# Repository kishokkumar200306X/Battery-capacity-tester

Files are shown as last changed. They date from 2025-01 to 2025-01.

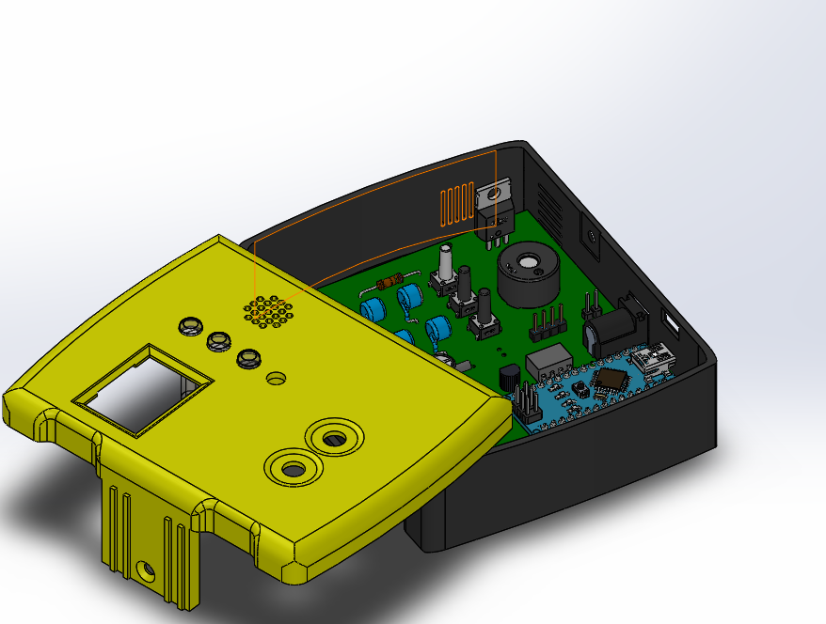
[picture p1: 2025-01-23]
image/Screenshot 2023-06-16 191335.png

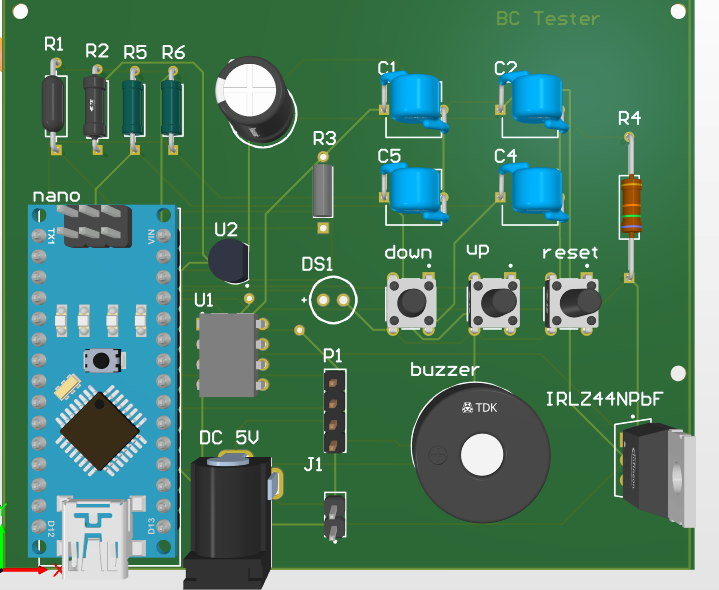
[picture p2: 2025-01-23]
image/Screenshot 2023-07-24 213903.png

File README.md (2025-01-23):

# Battery Capacity Tester

## Overview  
The Battery Capacity Tester is a digital device that allows users to measure the capacity of various battery types. It is designed for household use and works with nearly all batteries rated below 5V. The device features an OLED display for real-time monitoring and provides audible signals to indicate the start and end of the testing process.

## Main Functionality  
1. **Setup**  
   - Connect the battery to the battery terminal.  
   - Set the desired discharge current using the push buttons.  

2. **Start Test**  
   - Long-press the "UP" button until a beep is heard to start the test process.  

3. **Testing Process**  
   - The battery will discharge until its voltage reaches the low-level threshold of 3.2V.  
   - All relevant parameters (voltage, discharge current, and capacity) are displayed on the OLED during the process.  

4. **End of Test**  
   - Two prolonged beeps indicate the end of the test when the battery voltage drops to 3.2V.

Battrey capacity tester   

## Features  
- Supports a wide range of battery types:  
  - AA/AAA/NiMh/NiCd  
  - 18650 Li-ion  
  - Li-Polymer  
  - LiFePO4  
- Adjustable discharge current via push buttons.  
- Functions as an electronic load.  
- Real-time monitoring on a 0.96’’ I2C OLED display.  
- Audible alerts for the start and end of the test process.  

## Specifications  
- **Type**: Household battery tester  
- **Style**: Digital  
- **Power Supply**: 7–9V DC  
- **Display**: 0.96’’ I2C OLED  
- **Monitoring Parameters**:  
  - Battery voltage  
  - Discharge current  
  - Battery capacity  
- **Controls**:  
  - Three push buttons:  
    - One for resetting the Arduino  
    - Two for adjusting discharge current  
- **Buzzer**: Provides audible signals for key events.  
- **Operating Temperature**: 0°C – 40°C  

## How to Use  
1. Power the tester using a 7–9V DC power source.  
2. Connect the battery securely to the terminal.  
3. Use the push buttons to set the desired discharge current.  
4. Long-press the "UP" button to start the test.  
5. Monitor the OLED display for real-time updates on voltage, current, and capacity.  
6. Wait until the battery voltage reaches 3.2V, at which point the device will emit two prolonged beeps.  

## Notes  
- Ensure the power supply is stable and within the specified range (7–9V).  
- Operate the tester within the recommended temperature range (0°C – 40°C).  
- Handle batteries carefully to prevent short circuits or damage.  

---

**Enjoy accurate and efficient battery capacity testing with this versatile device!**

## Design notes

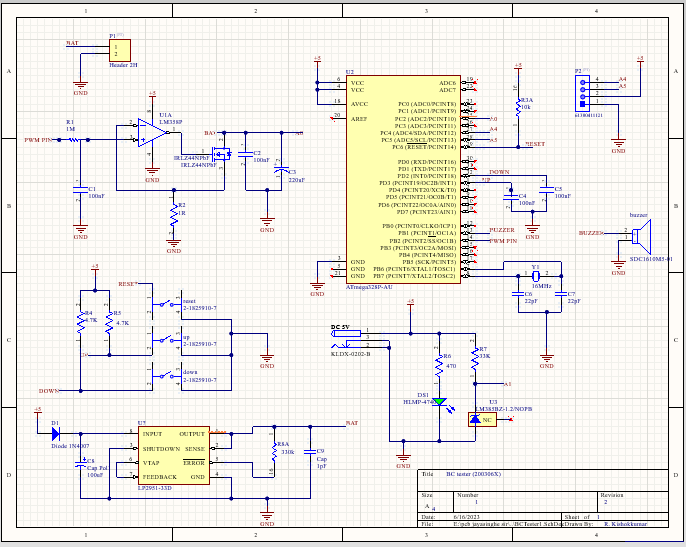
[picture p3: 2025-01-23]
image/Screenshot 2023-06-16 203310.png

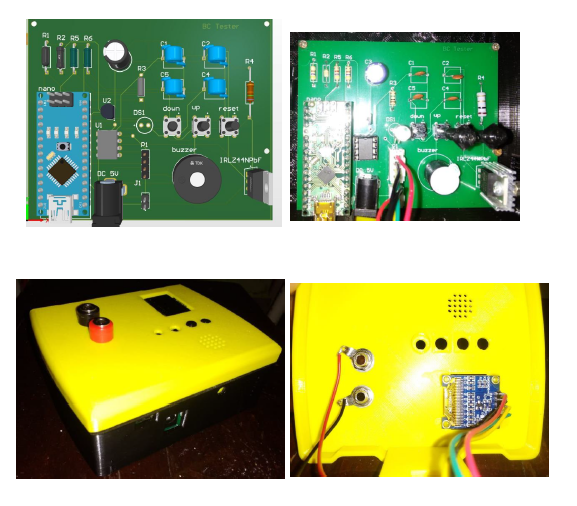
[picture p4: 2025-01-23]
image/implemeted .png

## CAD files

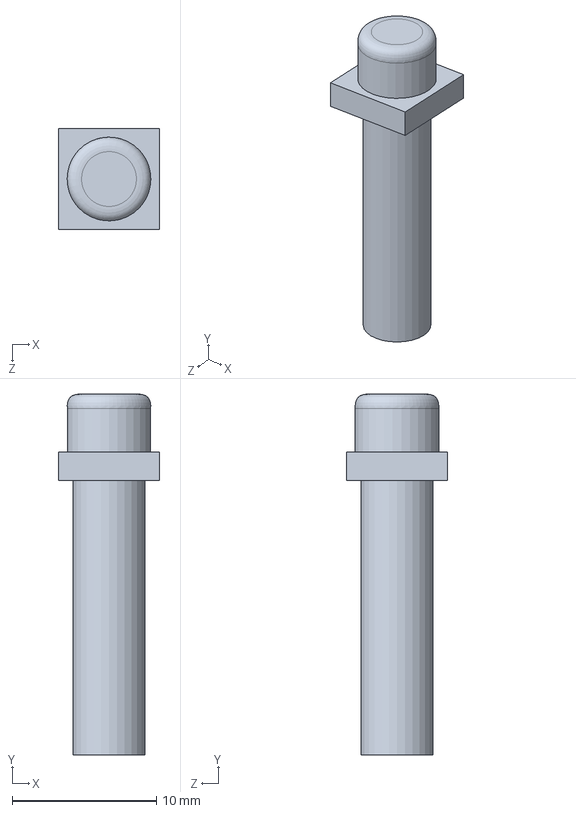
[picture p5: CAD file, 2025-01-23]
Enclosure design - solidworks/new sw.SLDPRT
7.00 x 25.0 x 7.00 mm

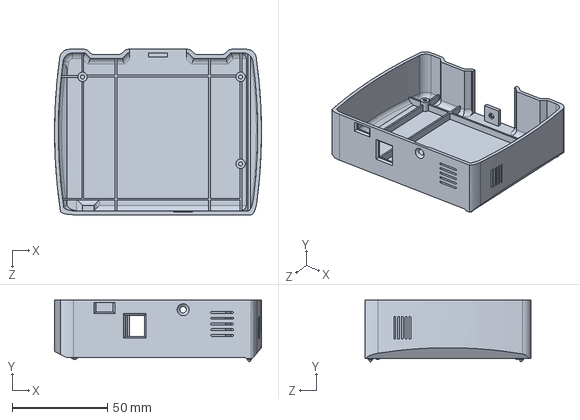
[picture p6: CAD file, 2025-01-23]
Enclosure design - solidworks/base.SLDPRT
108.8 x 32.4 x 87.0 mm

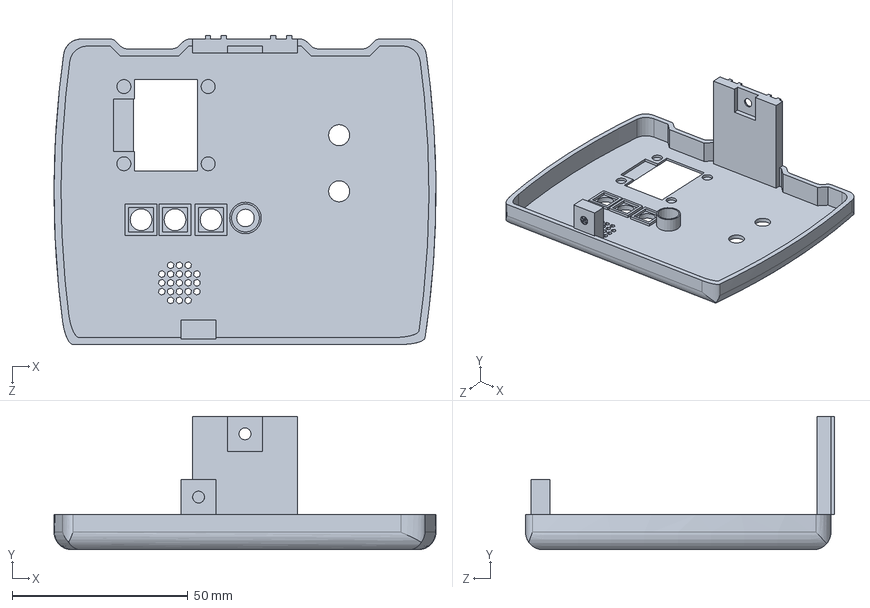
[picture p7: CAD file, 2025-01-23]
Enclosure design - solidworks/lid.SLDPRT
108.8 x 38.0 x 88.0 mm

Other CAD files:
Enclosure design - solidworks/base.STL
Enclosure design - solidworks/lid.STL
Enclosure design - solidworks/new sw.STL

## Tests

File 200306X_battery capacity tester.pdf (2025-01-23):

BATTERY CAPACITY TESTER

### DEPARTMENT OF ELECTRONICS AND TELECOMMUNICATION ENGINEERING

### UNIVERSITY OF MORATUWA

# EN2160 - Electronic Design Realization

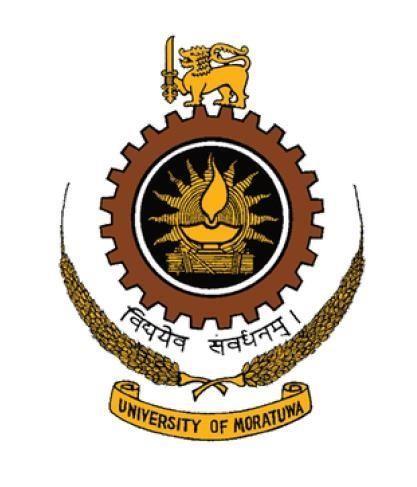
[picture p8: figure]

# Battery capacity tester

# Final Report

Kishokkumar R. – 200306X

## Main Function

The battery must be connected to the battery terminal. Long-press the "UP" button after setting the current to your specifications. The test procedure should then begin after hearing a beep. You will keep an eye on every parameter on the OLED display throughout the exam. Until its voltage approaches its low-level threshold, the battery will deplete. (3.2V). Two prolonged sounds will signal the end of the test process.

Features
Able to gauge AA/AA/NiMh/NiCd, 18650 Li-ion, Li-Polymer, and Li FePO4 battery capacities. It works with nearly all batteries with a rating of less than 5V. Pushbuttons can be used by users to adjust the discharge current.
User interface OLED
The gadget is capable of being an electronic load.

## Specifications

Type – household battery tester Style - digital
7-9V power supply required.
0.96’’ I2C OLED display.
Display battery voltage, Discharge current and Capacity.
Consists Three push buttons. One is use for reset the Arduino.
There is a buzzer
It indicates start and end of the test.
Working temperature : 0°C - 40°C

Product reference :
https://www.aliexpress.com/item/1005005105860242.html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 54628ea-1ad6-48d9-ad37-c57765e4c48d-16&pdp_npi=3%40dis%21LKR%2127385.19%2116431.76%21%21%21%21%21%40211bd7d61681041421921 8009d07f1%2112000031679811352%21sea%21LK%210&curPageLogUid=IA2RPzbEf1A6&ad_pvid=202 304090457014900265934220240003583604_17&ad_pvid=20230409045701490026593422024000 3583604_17 (https://www.aliexpress.com/item/1005005105860242.html?curPageLogUid=IA2RPzbEf1A6)

## Theory

The hypothesis is based on the voltage comparison of the OpAmp's unity amplifier-configured inverting (pin 2) and non-inverting (pin 3) inputs. The output of the opamp opens the gate of the MOSFET when the voltage applied to the non-inverting input is set by modifying the PWM signal. OpAmp receives negative feedback as the MOSFET turns on because of the voltage drop caused by the current flowing through R1 during this process. It manages the MOSFET in a way that ensures an identical voltage at both its inverting and non-inverting inputs. As a result, the voltage at the OpAmp's non-inverting input is directly proportional to the current flowing through the load resistor.

## Block diagram

User interface | outputs

Constant
current load
circuit

Arduino
nano board
Battery
voltage
measurement
circuit(voltage
sensing)

230V AC to 5V DC
Power supply

oled
display

3 -
switches[up,
down,reset]
(input)

Battery
terminals
(input)

Buzzer
circuit

## Pcb design files

Link for pcb design files- https://dms.uom.lk/s/4QDM4L8Pabeeqjx

1. Schematic design

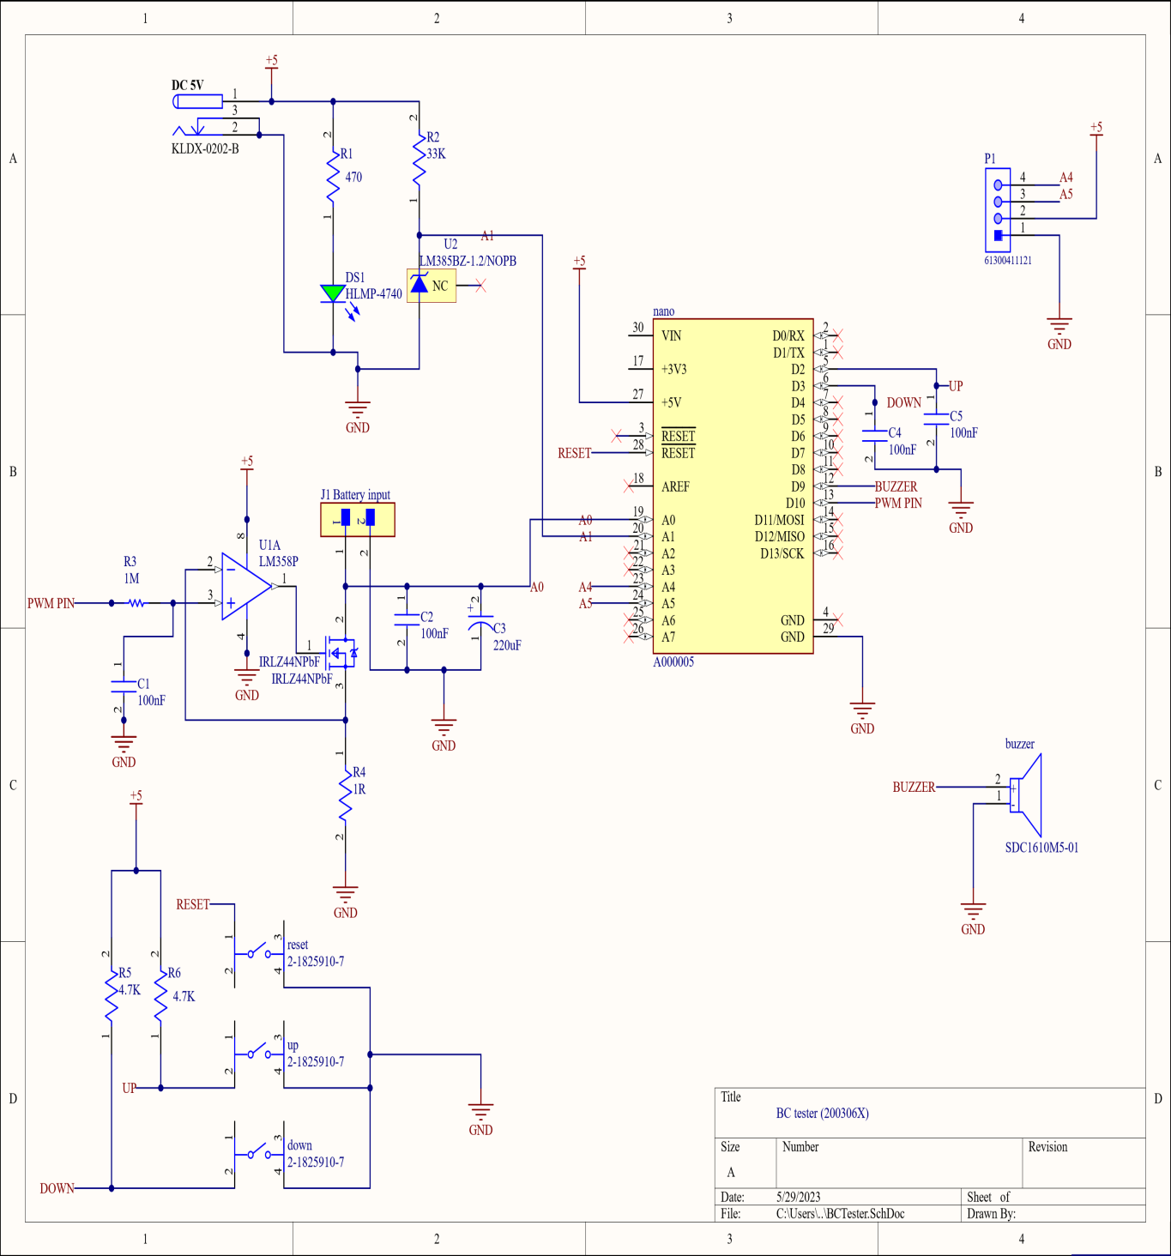
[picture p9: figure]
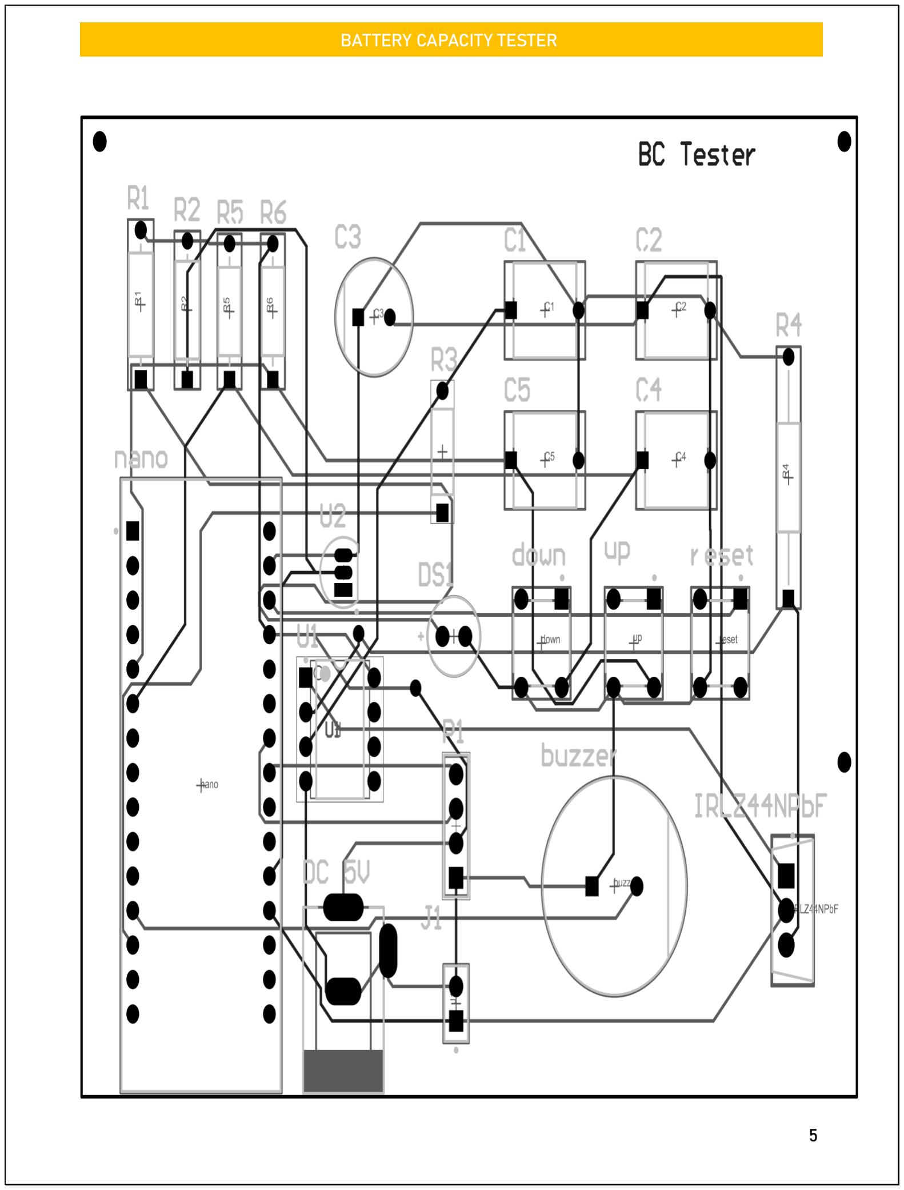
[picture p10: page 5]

## The following sections comprise the entire schematic:

1. A circuit with a constant current load

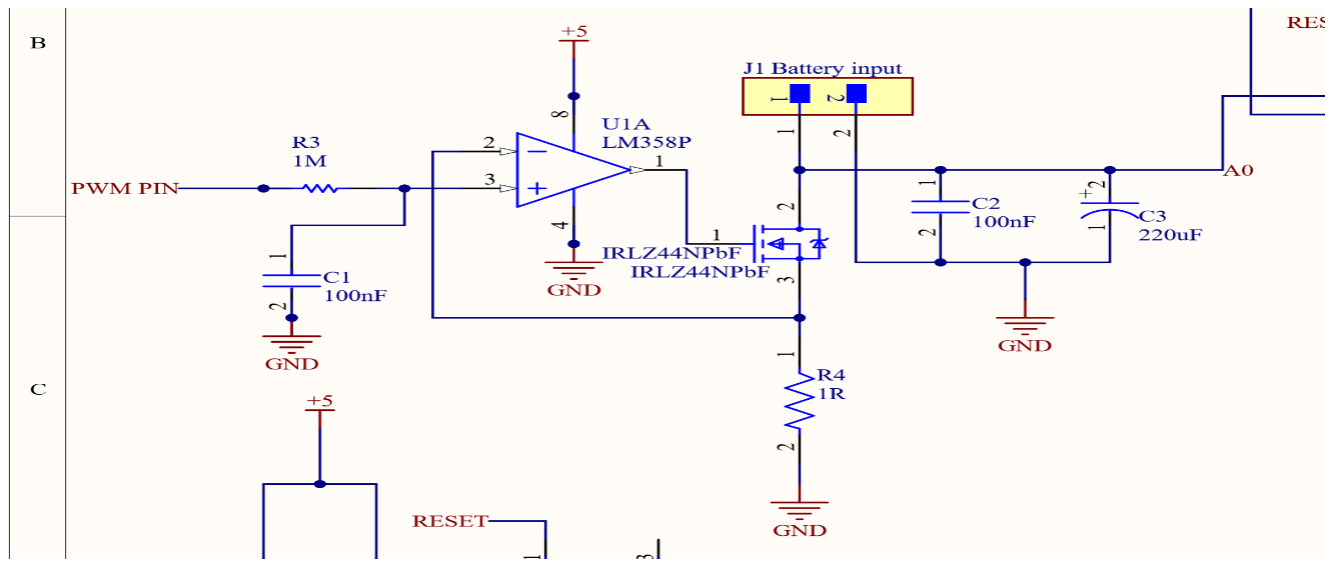
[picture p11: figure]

The LM358 dual amplifier is the project's major part. In a single box, the LM358 has two amplifiers. Only one op-amp is necessary for this project, though. The first operational amplifier's non-inverted pin is linked to the PWM output of Arduino Pin D10. To obtain an equivalent analogue voltage, the PWM is filtered using R3 and C1's low pass filter. The operational amplifier, which is linked to the IRLZ44N MOSFET source pin and the 1R shunt resistor (R4), receives feedback from the inverting input.

A constant current load circuit is created by this op-amp, R4, and the MOSFET. The opamp activates the MOSFET and tries to get the same voltage across R4 when the non-inverting input pin voltage is set. Because of Ohm's rule, a voltage drop must occur while current travels through the resistor. We can now adjust the PWM signal pulse width to control the current flowing through the load resistor (R3).

2. Circuit for Measuring Battery Voltage -

The Arduino's analogue input pin A0 measures the voltage of the battery. The constant current load circuit sounds, which can impair the efficiency of the ADC conversion, are filtered off using two capacitors, C2 and C3.

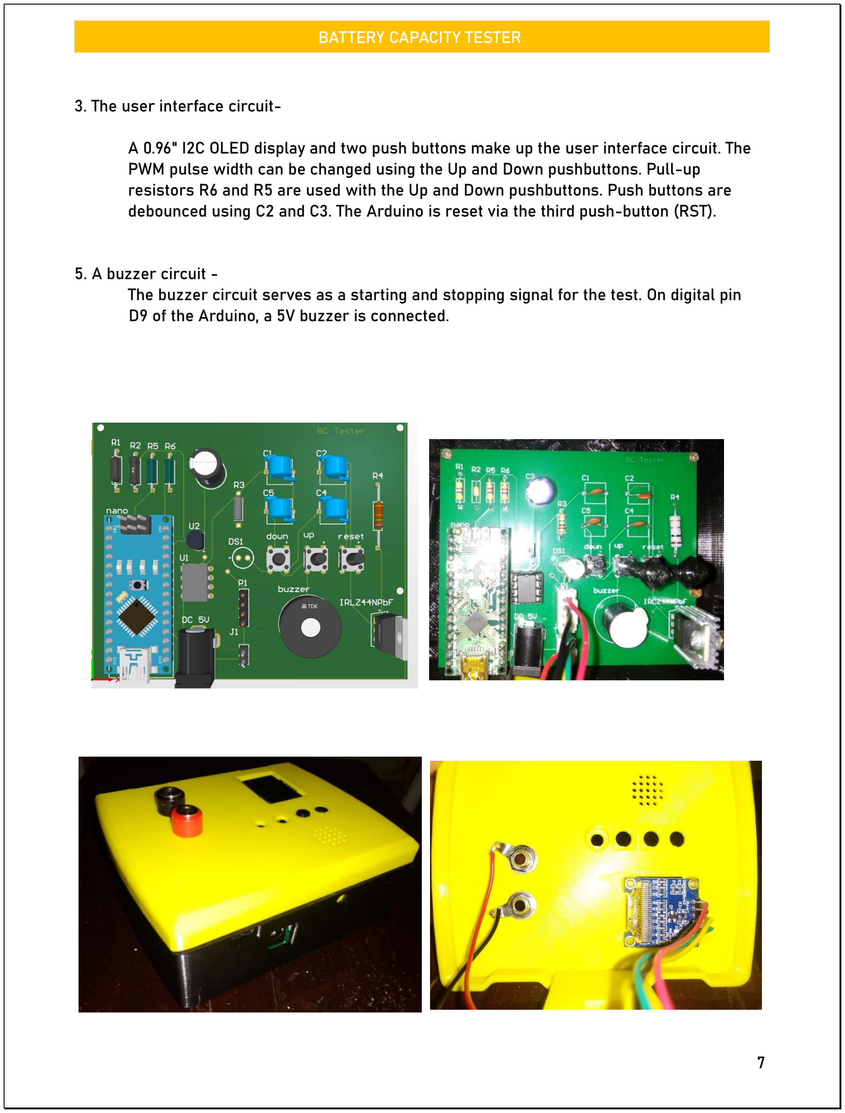
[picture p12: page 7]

3. The user interface circuit-

A 0.96" I2C OLED display and two push buttons make up the user interface circuit. The PWM pulse width can be changed using the Up and Down pushbuttons. Pull-up resistors R6 and R5 are used with the Up and Down pushbuttons. Push buttons are debounced using C2 and C3. The Arduino is reset via the third push-button (RST).

5. A buzzer circuit -
The buzzer circuit serves as a starting and stopping signal for the test. On digital pin D9 of the Arduino, a 5V buzzer is connected.

## Bill of materials

Mouser # | link | quantity | price | Manufacturer
782-A000005 | https://www.mouser.com
| /ProductDetail/782- A000005 (https://www.mouser.com/ProductDetail/782-A000005)
1 | $24.90
| | | | Arduino
926-LM385BZ- 12/NOPB | https://www.mouser.com
| /ProductDetail/926-
| LM385BZ-12-NOPB (https://www.mouser.com/ProductDetail/926-LM385BZ-12-NOPB)
3 | $3.48
| | | | Texas Instruments
595-LM358P | https://www.mouser.com
| /ProductDetail/595-
| LM358P (https://www.mouser.com/ProductDetail/595-LM358P)
4 | $1.52
| | | | Texas Instruments
942-IRLZ44NPBF | https://www.mouser.com
| /ProductDetail/942-
| IRLZ44NPBF (https://www.mouser.com/ProductDetail/942-IRLZ44NPBF)
2 | $3.32
| | | | Infineon
187- CL05A104KA5NN NC | https://www.mouser.com
| /ProductDetail/187-
| CL05A104KA5NNNC (https://www.mouser.com/ProductDetail/187-CL05A104KA5NNNC)
10 | $0.11
| | | | Samsung Electro-
| | | | Mechanics
80- ESK227M016AG3 DA | https://www.mouser.com /ProductDetail/80-
| ESK227M016AG3DA (https://www.mouser.com/ProductDetail/80-ESK227M016AG3DA)
10 | $2.57
| | | | KEMET
490-CMI-1295- 0585T | https://www.mouser.com
| /ProductDetail/490-CMI-
| 1295-0585T (https://www.mouser.com/ProductDetail/490-CMI-1295-0585T)
1 | $1.18
| | | | CUI Devices
708-CF14JT1M00 | https://www.mouser.com
| /ProductDetail/708-
| CF14JT1M00 (https://www.mouser.com/ProductDetail/708-CF14JT1M00)
10 | $0.31
| | | | SEI Stackpole
660- CFS1/4CT52R333J | https://www.mouser.com
| /ProductDetail/660-CFS1-
| 4CT52R333J (https://www.mouser.com/ProductDetail/660-CFS1-4CT52R333J)
10 | $0.46
| | | | KOA Speer
708-CF14JT4K70 | https://www.mouser.com
| /ProductDetail/708- CF14JT4K70 (https://www.mouser.com/ProductDetail/708-CF14JT4K70)
10 | $0.31
| | | | SEI Stackpole
279-CFR100J1M0 | https://www.mouser.com
| /ProductDetail/279-
| CFR100J1M0 (https://www.mouser.com/ProductDetail/279-CFR100J1M0)
10 | $2.62
| | | | TE Connectivity
815-ABLS-16.0M- T | https://www.mouser.com
| /ProductDetail/815-ABLS-
| 16.0M-T (https://www.mouser.com/ProductDetail/815-ABLS-16.0M-T)
2 | $0.64
| | | ABRACON

## Enclosure design files

Link for solidworks files - https://dms.uom.lk/s/D8EcxXdq78NAgSy

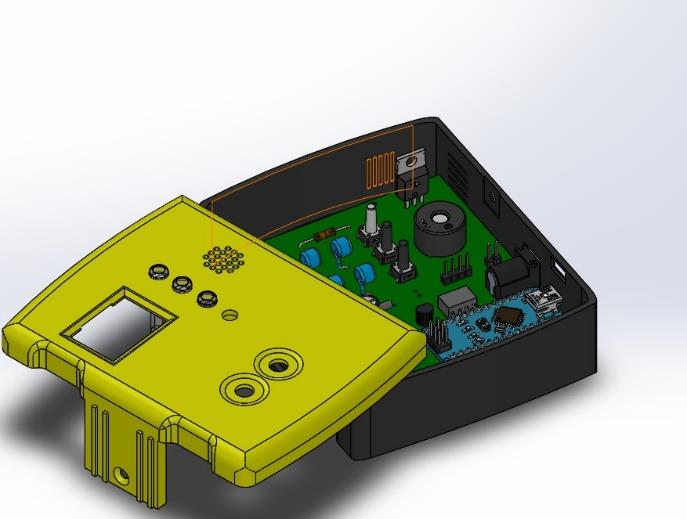
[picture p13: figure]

## Arduino codes

Link -https://dms.uom.lk/s/RrMbTZdH6JyfaTf

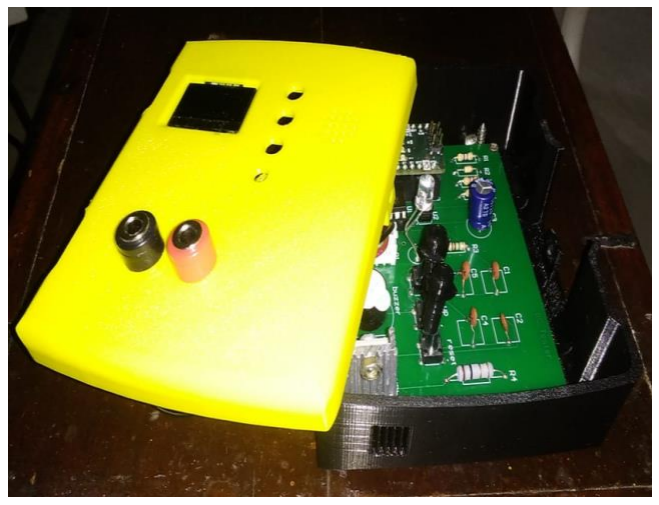
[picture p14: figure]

## User manual

### Procedure

1. Power up the device through power supply (device automatically ask to set the discharge current )

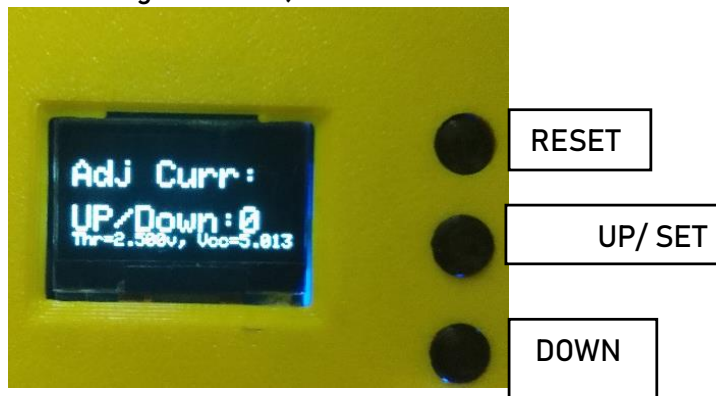
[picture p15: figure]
RESET; UP/ SET; DOWN

2. User can set discharge current according to the up and down buttons and set the discharging current through long press the up buttons.
3. Once device get the battery capacity then it will make sound to indicate it.
4. Display shows the time taken for process , instance voltage across the battery and capacity.

### Precautions

1. User should connect the terminals correctly.
2. Keep the device around 27degree Celsius environment.
3. Double-check the battery capacity tester to make sure it is appropriate for the particular battery chemistry and voltage you plan to test. Inaccurate results or battery damage can result from using the improper tester.
4. Before testing, check the battery for physical damage, leakage, or swelling. Batteries that are obviously degraded or damaged shouldn't be tested because they pose a risk.

## Maintenance procedure

For a battery capacity tester to remain accurate and dependable, proper maintenance is essential. Regular upkeep increases a device's lifespan and guarantees that it will operate properly when required. For a battery capacity tester, the following general maintenance methods are recommended:

1. Examine the manual:
a. Read the manufacturer's given user manual in its entirety first. The manual often includes detailed schedules and directions for maintenance.
2. Maintain Regular Cleaning:
a. Wipe the battery capacity tester clean by using a soft, dry cloth. Clear the device's surface of any dust, grime, or debris that may have accumulated.
3. Examine Testing Cables and Connectors:
a. Consistently look for evidence of wear, damage, or loose connections on the testing cables and connectors. In order to prevent false readings, damaged wires should be replaced right away.
4. Calibration Check:
a. As directed by the manufacturer or based on usage patterns, do routine calibration checks. The accuracy of the tester's readings is guaranteed via calibration.
5. Software update:
a. Updates to the battery capacity tester's software should be installed as needed. If the battery capacity tester has software or firmware, look for updates from the manufacturer. Software updates may enhance functionality and include new features.
6. Maintain a Proper Environment:
a. The battery capacity tester should be kept in a sterile, dry, and temperaturecontrolled environment. The device can be harmed by high or low humidity, exposure to liquids, or extreme temperatures.

7. Packaging :
a. Use a protective carrying case or storage bag, if at all possible, to keep the battery capacity tester safe during transportation and when not in use.
8. Service and repairs:
a. For maintenance and repairs on the battery capacity tester, get in touch with the manufacturer's authorised service centre. Avoid making repairs on your own as this could void the warranty or cause more harm.
9. User Handling:
a. Educate users on how to use and handle the battery capacity tester correctly. Do not drop or handle the gadget roughly as this could lead to internal damage.
10. Follow manufacturer's instructions:
a. Follow any maintenance advice the manufacturer may provide you. To ensure peak performance, they could provide particular advises or recommendations.
11. Regular Testing:
a. To ensure the battery capacity tester's accuracy, test it on a regular basis with reference batteries that are known to work. This makes it possible to detect any reading drift and make corrections as necessary.

## Performance verification

1. Reference battery test :
a. Use a set of reference batteries that are well-known, completely charged, and have capacities that have been independently validated. Record the measurements after each reference battery is connected to the tester. Compared to the reference batteries' known capacity, compare the tester's findings. Within a reasonable tolerance range, the tester should deliver readings that are somewhat near to the known values.
2. Verification with New Batteries:
a. Utilise the capacity tester to test new batteries with the appropriate capacities. For the batteries being tested, the measurements must closely resemble the capacity specified by the manufacturer.
3. Test for repeatability:
a. Run the same battery through several tests in a row, then compare the findings. The readings ought to be reliable and barely deviate.
4. Linearity test:
a. Test batteries' linearity using a range of capacities, from low to high. The readings from the tester should show a linear relationship with the tested battery capacity.
5. Temperature sensitivity:
a. Test batteries' sensitivity to temperature variations within the device's operational range. Regardless of temperature variations, the tester should display consistent values.
6. Internal Battery Test:
a. If the battery capacity tester includes a built-in battery for backup power, regularly check its capacity to make sure it has enough power.

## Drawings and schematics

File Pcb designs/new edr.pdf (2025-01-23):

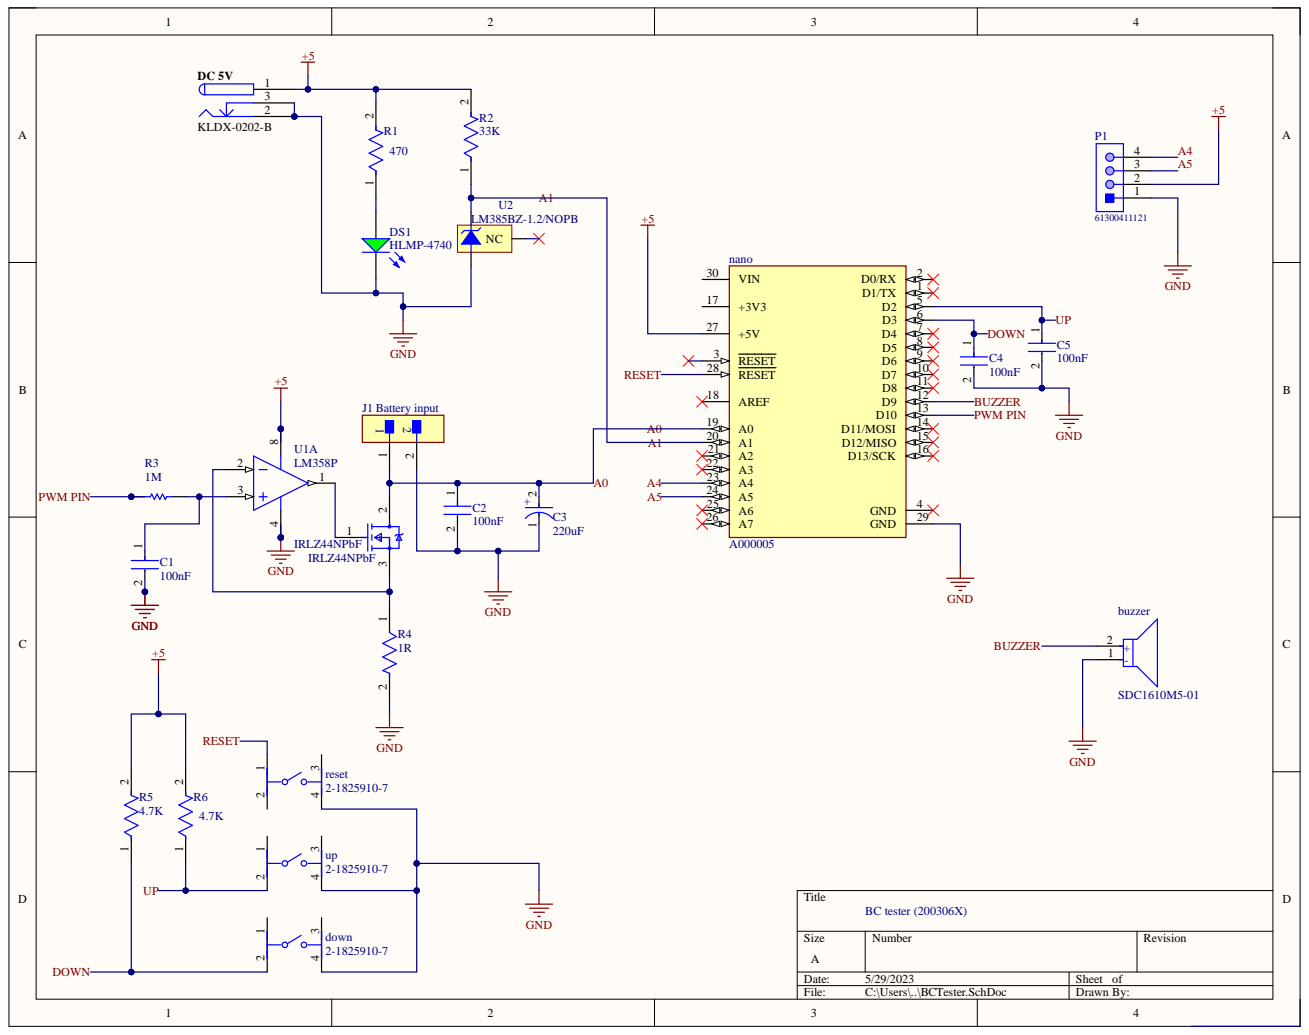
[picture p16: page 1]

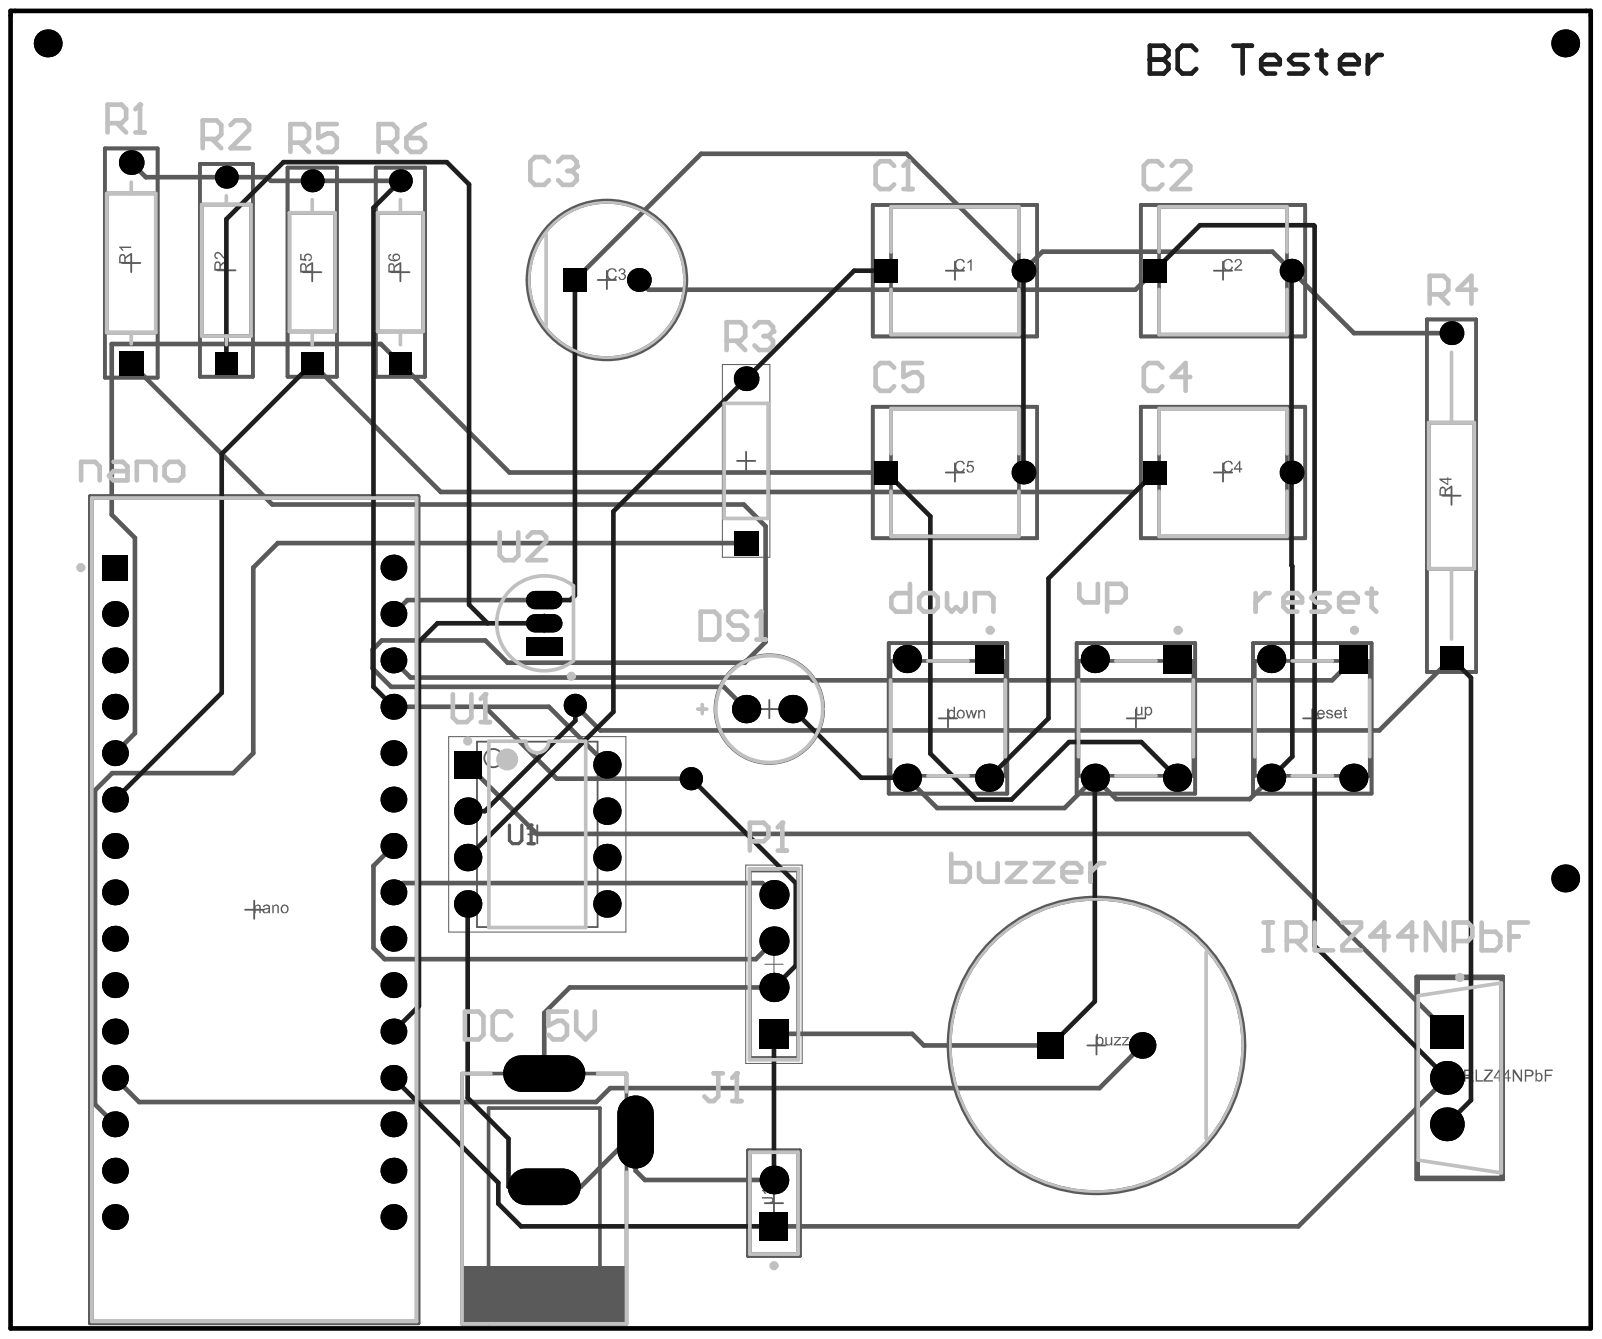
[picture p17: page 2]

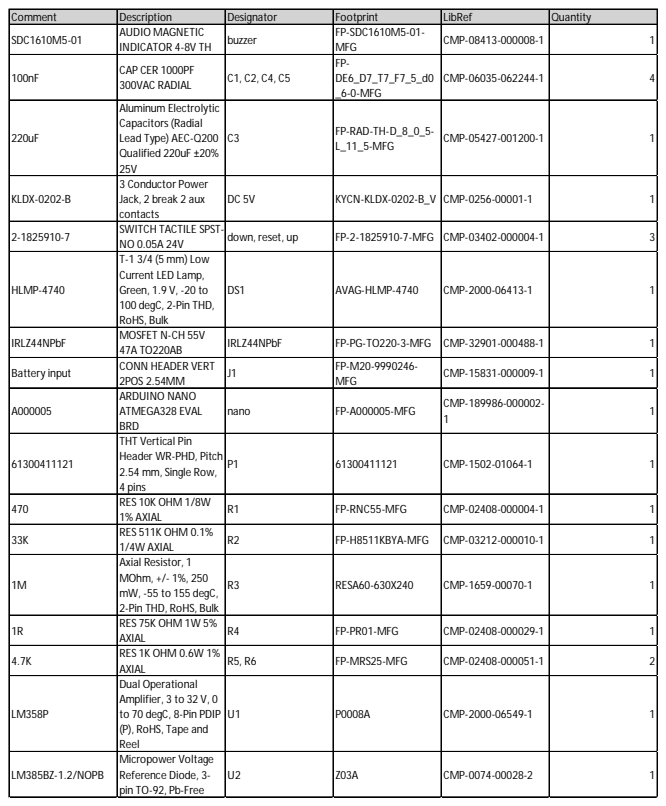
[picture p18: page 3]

Comment | Description | Designator | Footprint | LibRef | Quantity
SDC1610M5-01 | AUDIO MAGNETIC INDICATOR 4-8V TH | buzzer | FP-SDC1610M5-01-MFG | CMP-08413-000008-1 | 1

100nF | CAP CER 1000PF 300VAC RADIAL | C1, C2, C4, C5 | FP-DE6_D7_T7_F7_5_d0 _6-0-MFG | CMP-06035-062244-1 | 4

220uF | Aluminum Electrolytic Capacitors (Radial Lead Type) AEC-Q200 Qualified 220uF ±20% 25V | C3 | FP-RAD-TH-D_8_0_5-L_11_5-MFG | CMP-05427-001200-1 | 1

KLDX-0202-B | 3 Conductor Power Jack, 2 break 2 aux contacts | DC 5V | KYCN-KLDX-0202-B_V | CMP-0256-00001-1 | 1

2-1825910-7 | SWITCH TACTILE SPST-NO 0.05A 24V | down, reset, up | FP-2-1825910-7-MFG | CMP-03402-000004-1 | 3

HLMP-4740 | T-1 3/4 (5 mm) Low Current LED Lamp, Green, 1.9 V, -20 to 100 degC, 2-Pin THD, RoHS, Bulk | DS1 | AVAG-HLMP-4740 | CMP-2000-06413-1 | 1

IRLZ44NPbF | MOSFET N-CH 55V 47A TO220AB | IRLZ44NPbF | FP-PG-TO220-3-MFG | CMP-32901-000488-1 | 1

Battery input | CONN HEADER VERT 2POS 2.54MM | J1 | FP-M20-9990246-MFG | CMP-15831-000009-1 | 1

A000005 | ARDUINO NANO ATMEGA328 EVAL BRD | nano | FP-A000005-MFG | CMP-189986-000002-1 | 1

61300411121 | THT Vertical Pin Header WR-PHD, Pitch 2.54 mm, Single Row, 4 pins | P1 | 61300411121 | CMP-1502-01064-1 | 1

470 | RES 10K OHM 1/8W 1% AXIAL | R1 | FP-RNC55-MFG | CMP-02408-000004-1 | 1

33K | RES 511K OHM 0.1% 1/4W AXIAL | R2 | FP-H8511KBYA-MFG | CMP-03212-000010-1 | 1

1M | Axial Resistor, 1 MOhm, +/- 1%, 250 mW, -55 to 155 degC, 2-Pin THD, RoHS, Bulk | R3 | RESA60-630X240 | CMP-1659-00070-1 | 1

1R | RES 75K OHM 1W 5% AXIAL | R4 | FP-PR01-MFG | CMP-02408-000029-1 | 1

4.7K | RES 1K OHM 0.6W 1% AXIAL | R5, R6 | FP-MRS25-MFG | CMP-02408-000051-1 | 2

LM358P | Dual Operational Amplifier, 3 to 32 V, 0 to 70 degC, 8-Pin PDIP (P), RoHS, Tape and Reel | U1 | P0008A | CMP-2000-06549-1 | 1

LM385BZ-1.2/NOPB | Micropower Voltage Reference Diode, 3-pin TO-92, Pb-Free | U2 | Z03A | CMP-0074-00028-2 | 1

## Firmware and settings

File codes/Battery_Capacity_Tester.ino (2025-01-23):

#include <Adafruit_GFX.h>
#include <Adafruit_GrayOLED.h>
#include <Adafruit_SPITFT.h>
#include <Adafruit_SPITFT_Macros.h>
#include <gfxfont.h>





    //>>>>>>>>>>>>>>>>>>>>>>>>>>>>>>>>>>>>>>>>>>>>>>>>>>>>>
    // ARDUINO BATTERY CAPACITY TESTER
    
    
    #include<JC_Button.h>
    #include <Adafruit_SSD1306.h>
    
    #define DEBUG 0 // Binary Treatment 0=Nothing, 1=Early, 2=Running Voltages, 4=Finish
    #define SCREEN_WIDTH 128 // OLED display width, in pixels
    #define SCREEN_HEIGHT 64 // OLED display height, in pixels
    
    // Declaration for an SSD1306 display connected to I2C (SDA, SCL pins)
    #define OLED_RESET 4 // Reset pin # (or -1 if sharing Arduino reset pin)
    Adafruit_SSD1306 display(SCREEN_WIDTH, SCREEN_HEIGHT, &Wire, OLED_RESET);
    
    void timerInterrupt();
    void Display_UP_DOWN();//Debugging support
    void Print_DEBUG_4();//Debugging support
    
    const float Low_BAT_level = 2.50;// Threshold for stopping test
    //Desired Current steps with a 3R load (R7)
    int Current [] = {0,50,100,200,300,400,500,600,700,800,900,1000};
    int PWM [] = {0, 2, 5, 10, 15, 20, 25, 30, 35, 40, 45, 50};
    int Array_Size;// calculated during setup
    const byte PWM_Pin = 10;
    const byte Buzzer = 9;
    const int BAT_Pin = A0;
    const int Vref_Pin = A1;//Pin to which Band Gap Reference is attached
    int Current_Value = 0; // Selected Current value for test
    int PWM_Value = 0;// Value of PWM during test
    int PWM_Index = 0;// Index into PWM array during test
    unsigned long Capacity;
    float Capacity_f;
    int ADC_Value = 0;
    float Vref_Voltage = 1.215; // LM385BLP-1.2 Band Gap Reference voltage
    float Vcc = 4.94; // Voltage of Arduino 5V pin ( Measured during setup using Band Gap Reference )
    float BAT_Voltage = 0;
    float Resistance = 1.0; // Value of R3 Power Resistor
    float sample = 0;
    byte Hour = 0, Minute = 0, Second = 0;
    bool calc = false, Done = false, Report_Info = true;
    Button UP_Button(2, 25, false, true);
    Button Down_Button(3, 25, false, true);
    
    // string values for reporting intermediate information
    const int VAL_MAX = 10;
    char val_0[VAL_MAX]={""};
    char val_2[VAL_MAX]={""};
    
    void setup () {//Setup
    
    Serial.begin(38400);
    pinMode(PWM_Pin, OUTPUT);
    pinMode(Buzzer, OUTPUT);
    analogWrite(PWM_Pin, PWM_Value);
    UP_Button.begin();
    Down_Button.begin();
    display.begin(SSD1306_SWITCHCAPVCC, 0x3C);
    display.clearDisplay();
    display.setTextColor(WHITE);
    display.setTextSize(2);
    display.setCursor(12,25);
    display.print("BC TESTER");
    display.display();
    delay(3000);
    display.clearDisplay();
    display.setTextSize(2);
    display.setCursor(2,15);
    display.print("Adj Curr:");
    display.setCursor(2,40);
    display.print("UP/Down:");
    display.print("0");
    display.setCursor(2,55);
    display.setTextSize(1);
    
    #if (DEBUG == 1 || DEBUG == 5)
    Serial.println("\nStart of calculations");
    #endif
    
    Array_Size = sizeof(Current)/2;
    //Read voltages of Band Gap Reference and use it to calculate actual Vcc
    float fTemp=0.0;
    for(int i=0;i< 100;i++)
    {
    fTemp=fTemp+analogRead(Vref_Pin); //read the Band Gap Reference voltage
    delay (2);
    }
    fTemp=fTemp/100.0;
    Vcc = Vref_Voltage * 1024.0 / fTemp;
    
    // Convert desired current levels to PWM using actual Vcc
    // Convert PWM values back to actual current levels
    // While measuring actual current I discovered that the actual draw is
    // (PWM + 1)/256 rather than PWM/255 as indicated in Arduino documentation
    int iTemp;
    for (int i=0;i<Array_Size;i++)
    {
    iTemp = int( Resistance * Current[i] * 256.0 / Vcc / 1000.0 - 1.0 + 0.5 ); // desired current to nearest PWM
    iTemp = min(iTemp,255);
    iTemp = max(iTemp,0);
    Current[i] = int( (iTemp+1) * Vcc / 256.0 / Resistance * 1000.0); // actual current for PWM
    PWM[i] = iTemp;//Save PWM in array
    }
    
    //Include Threshold and Vcc in startup display
    dtostrf(Low_BAT_level, 5, 3, val_0);
    dtostrf(Vcc, 5, 3, val_2);
    
    display.print("Thr=");
    display.print(val_0);
    display.print("v, Vcc=");
    display.print(val_2);
    
    display.display();
    display.setTextSize(2);
    
    }//Setup
    
    //************************* End of Setup function *******************************
    
    void loop() {
    
    if (Report_Info)
    {//Report_Info
    Serial.flush();
    #if (DEBUG == 1 || DEBUG == 5)
    // Serial.println("Measured Vcc Voltage: " + String(Vcc) + " volts");
    Serial.print("Threshold: ");
    Serial.print(Low_BAT_level,3);
    Serial.println(" volts");
    Serial.print("R3 Resistance: ");
    Serial.print(Resistance,3);
    Serial.println(" ohms");
    Serial.print("Measured Vcc Voltage: ");
    Serial.print(Vcc,4);
    Serial.println(" volts");
    sample = 0.0;
    
    Serial.println("Index Actual(mA) PWM");
    for (int i=0;i<Array_Size;i++)
    {
    // Serial.println( "["+String(i)+"]="+String(Current[i])+" mA PWM["+String(i)+"]="+String(PWM[i]) );
    Serial.print("[");
    Serial.print(i);
    Serial.print("]");
    Serial.print(" ");
    Serial.print(Current[i],DEC);
    Serial.print(" ");
    Serial.print(PWM[i],DEC);
    Serial.println(" ");
    }
    #endif
    Report_Info = false;
    }//Report_Info
    
    UP_Button.read();
    Down_Button.read();
    if (UP_Button.wasReleased() && PWM_Index < (Array_Size-1) && calc == false)
    {
    PWM_Value = PWM[++PWM_Index];
    analogWrite(PWM_Pin,PWM_Value);
    
    Display_UP_DOWN();
    }
    
    if (Down_Button.wasReleased() && PWM_Index > 0 && calc == false)
    {
    PWM_Value = PWM[--PWM_Index];
    analogWrite(PWM_Pin,PWM_Value);
    
    Display_UP_DOWN();
    }
    
    if (UP_Button.pressedFor (1000) && calc == false)
    {
    digitalWrite(Buzzer, HIGH);
    delay(100);
    digitalWrite(Buzzer, LOW);
    display.clearDisplay();
    timerInterrupt();
    }
    }
    
    //************************* End of Loop function *******************************
    
    void timerInterrupt(){
    calc = true;
    while (Done == false) {//(Done == false)
    Second ++;
    if (Second == 60) {
    Second = 0;
    Minute ++;
    }
    if (Minute == 60) {
    Minute = 0;
    Hour ++;
    }
    
    //************ Measuring Battery Voltage ***********
    
    for(int i=0;i< 100;i++)
    {
    sample=sample+analogRead(BAT_Pin); //read the Battery voltage
    delay (2);
    }
    sample=sample/100;
    BAT_Voltage = sample * Vcc / 1024.0;
    //*********************************************
    
    display.clearDisplay();
    display.setTextSize(2);
    display.setCursor(20,5);
    // display.print(String(Hour) + ":" + String(Minute) + ":" + String(Second));
    display.print(Hour);
    display.print(":");
    display.print(Minute);
    display.print(":");
    display.print(Second);
    
    display.setTextSize(1);
    display.setCursor(0,25);
    display.print("Disch Curr: ");
    // display.print(String(Current[PWM_Index])+"mA");
    display.print(Current_Value);
    display.print("mA");
    
    display.setCursor(2,40);
    // display.print("Bat Volt:" + String(BAT_Voltage)+"V" );
    display.print("Bat Volt:");
    display.print(BAT_Voltage,3);
    display.print("V");
    
    // When total seconds is greater than 32767 the statement below did not work until the byte values
    // Hour, Minute and Second were cast to an unsigned long. Apparently the compiler cast the byte
    // values to an "int" first which cannot represent 32768 correctly
    Capacity = ((unsigned long)Hour * 3600) + ((unsigned long)Minute * 60) + (unsigned long)Second;
    Capacity_f = ((float)Capacity * Current_Value) / 3600.0;
    
    display.setCursor(2, 55);
    // display.print("Capacity:" + String(Capacity) + "mAh");
    display.print("Capacity:");
    display.print(Capacity_f,1);
    display.print("mAh");
    display.display();
    
    #if (DEBUG == 4 || DEBUG == 2)
    Print_DEBUG_4();
    #endif
    
    if (BAT_Voltage < Low_BAT_level)
    {//BAT_Voltage < Low_BAT_level
    
    #if (DEBUG == 4 || DEBUG == 5)
    Serial.println("\nCurrent_Value PWM_Value");
    Serial.print(Current_Value);
    Serial.print(" ");
    Serial.println(PWM_Value);
    Serial.println("\nHour Minute Second PWM_Index");
    Serial.print(Hour);
    Serial.print(" ");
    Serial.print(Minute);
    Serial.print(" ");
    Serial.print(Second);
    Serial.print(" ");
    Serial.println(PWM_Index);
    #endif
    
    // When total seconds is greater than 32767 the statement below did not work until the byte values
    // Hour, Minute and Second were cast to an unsigned long. Apparently the compiler cast the byte
    // values to an "int" first which cannot represent 32768 correctly
    Capacity = ((unsigned long)Hour * 3600) + ((unsigned long)Minute * 60) + (unsigned long)Second;
    
    #if (DEBUG == 4 || DEBUG == 5)
    Serial.println("Capacity HMS");
    Serial.println(Capacity);
    #endif
    
    Capacity_f = ((float)Capacity * Current_Value) / 3600.0;
    
    #if (DEBUG == 4 || DEBUG == 5)
    Serial.println("Capacity HMS*PWM");
    Serial.println(Capacity_f,1);
    #endif
    
    display.clearDisplay();
    display.setTextSize(2);
    display.setCursor(2,15);
    display.print("Capacity:");
    display.setCursor(2,40);
    // display.print(String(Capacity) + "mAh");
    display.print(Capacity_f,1);
    display.print("mAh");
    display.display();
    Done = true;
    PWM_Value = 0;
    analogWrite(PWM_Pin, PWM_Value);
    digitalWrite(Buzzer, HIGH);
    delay(100);
    digitalWrite(Buzzer, LOW);
    delay(100);
    digitalWrite(Buzzer, HIGH);
    delay(100);
    digitalWrite(Buzzer, LOW);
    delay(100);
    }//BAT_Voltage < Low_BAT_level
    delay(1000);
    }//(Done == false)
    
    }// timerInterrupt
    
    void Display_UP_DOWN()
    {//Display_UP_DOWN()
    Current_Value = Current[PWM_Index];
    
    display.clearDisplay();
    display.setCursor(2,25);
    display.print("Curr:");
    display.print(Current_Value);
    display.print("mA ");
    display.setCursor(2,40);
    display.print("PWM=");
    display.print(PWM_Value);
    display.display();
    }//Display_UP_DOWN()
    
    void Print_DEBUG_4()
    {//Print_DEBUG_4()
    Serial.print(Hour);
    Serial.print(":");
    Serial.print(Minute);
    Serial.print(":");
    Serial.print(Second);
    Serial.print(" ");
    Serial.print(BAT_Voltage,3);
    Serial.print("v ");
    Serial.print(Capacity_f,1);
    Serial.println("mAh");
    }//Print_DEBUG_4()
